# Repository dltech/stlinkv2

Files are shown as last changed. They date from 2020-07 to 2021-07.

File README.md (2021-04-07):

# stlinkv2
ST-link V2 schematic and PCB in kiCAD with initial firmware through UART.
1. PCB templates for prototyping at home are photoresist.svg and lut.svg, also you can convert PCB to any of appropriate formats using KiCAD.
2. As you seen above, for this solution you do not need any other st-link, you need only usb-uart adapter.
3. When you got a board, pull up pin 44 BOOT0 to Vbus by R4 resistor, so after power connect the MCU starts up from the UART bootloader.
4. Power up board by USB and connect it to your PC through UART by RX and TX pads.
5. Write dummy firmware from STLinkV2_bin.zip using the flasher utility (ST UM0462).
6. Return pull down resistor to pin 44 BOOT0 (change location of 10-100K resistor from R4 to R5 place).
7. Then connect it to USB and write the firmware from ST using upgrade utility stlink-V2.J21.S4.zip. Now you got a working st-link clone.

On the linux using the Virtualbox software this method is working too.
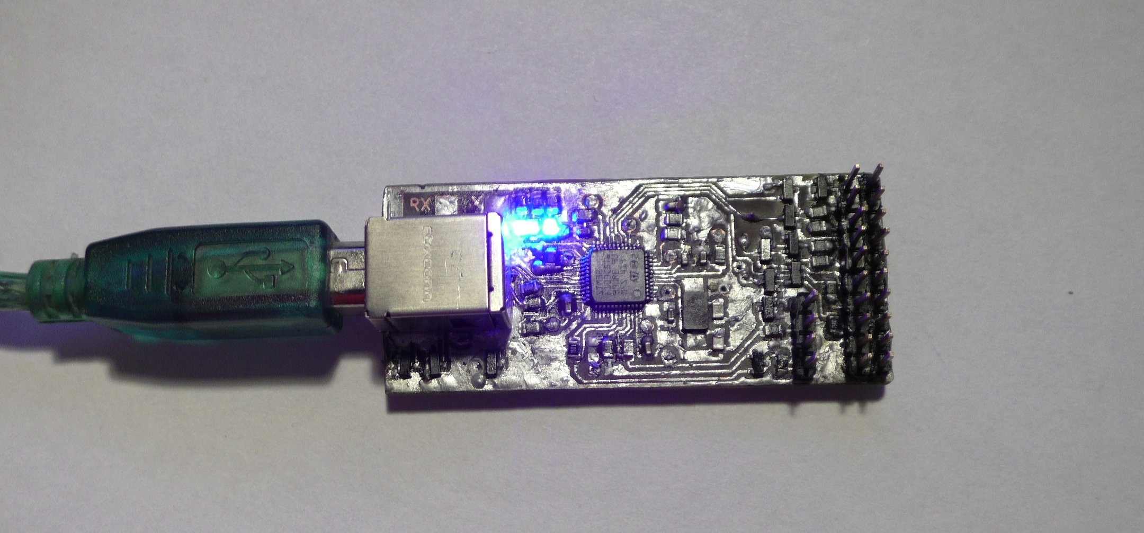
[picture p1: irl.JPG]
device


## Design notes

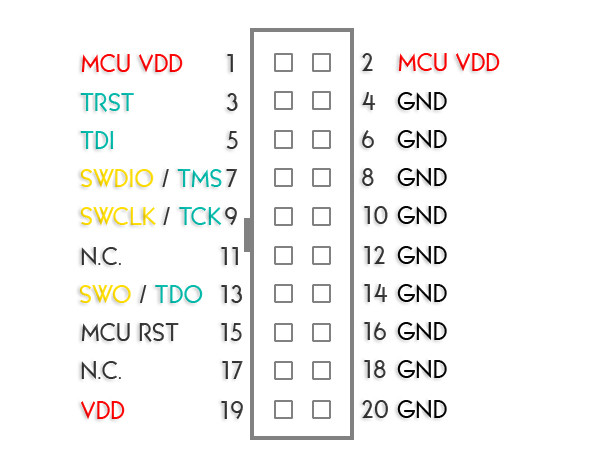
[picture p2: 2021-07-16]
jtag pinout.jpg

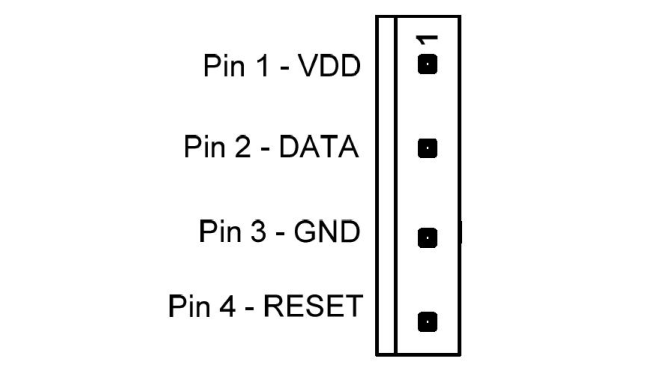
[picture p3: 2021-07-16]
swimm pinout.png

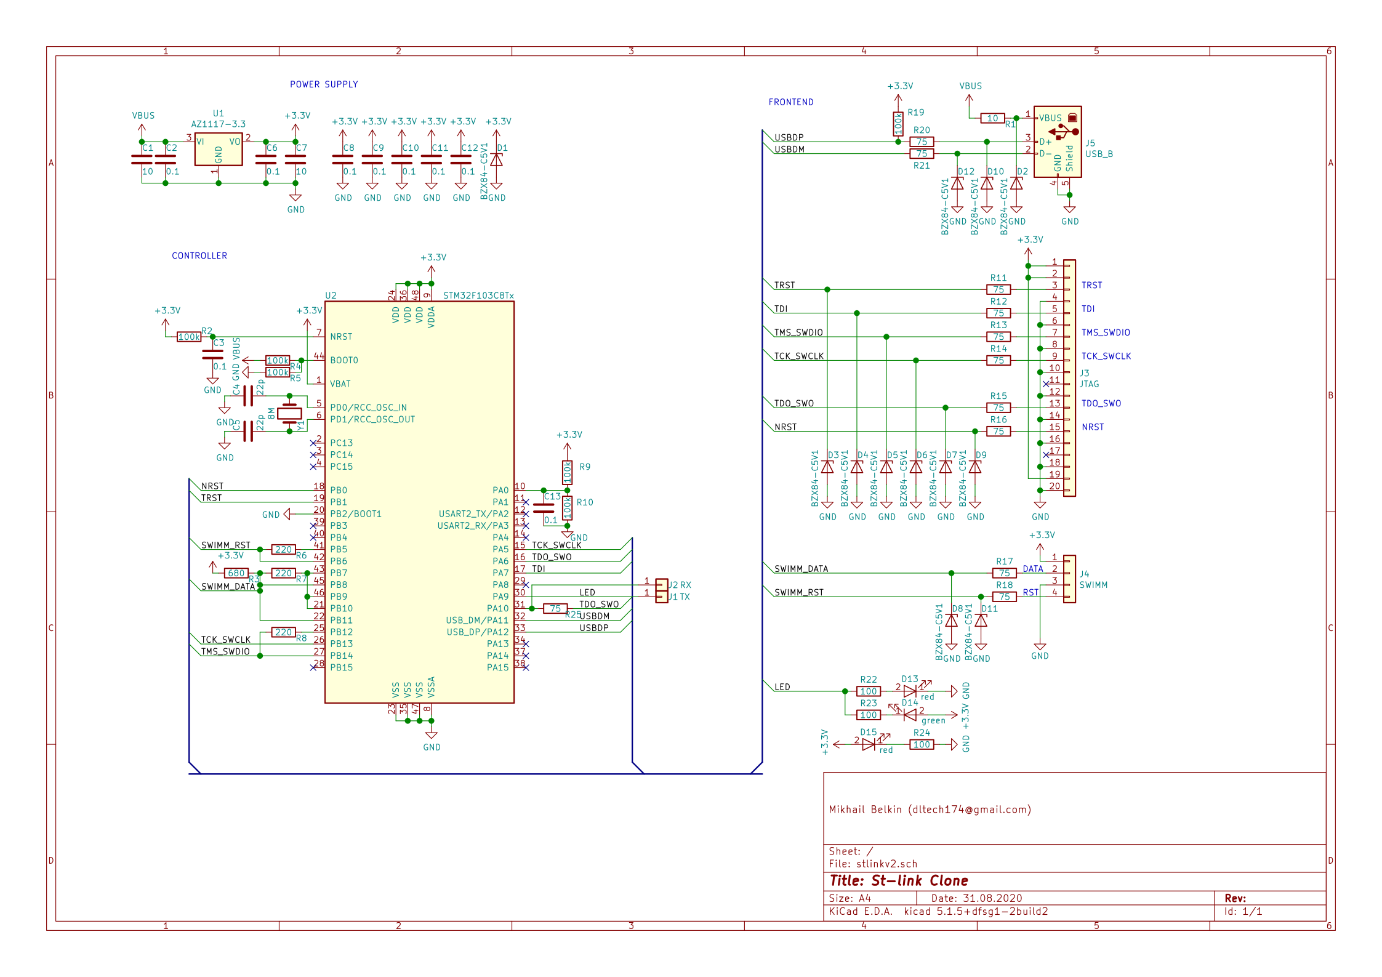
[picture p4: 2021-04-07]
schematic.png

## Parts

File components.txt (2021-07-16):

stm32f103c8t6	x1
BZX85-C5V1	x12
0805 LED	x3 
AMS1117-3.3	x1
8MHZ 5032	x1
0805 CAP 10uF	x2
0805 CAP 0.1uF	x9
0805 CAP 22pF	x2
0805 RES 10	x1
0805 RES 75	x10
0805 RES 100	x3
0805 RES 220	x4
0805 RES 100k	x6
PLS 2.54	x24
USB B		x1

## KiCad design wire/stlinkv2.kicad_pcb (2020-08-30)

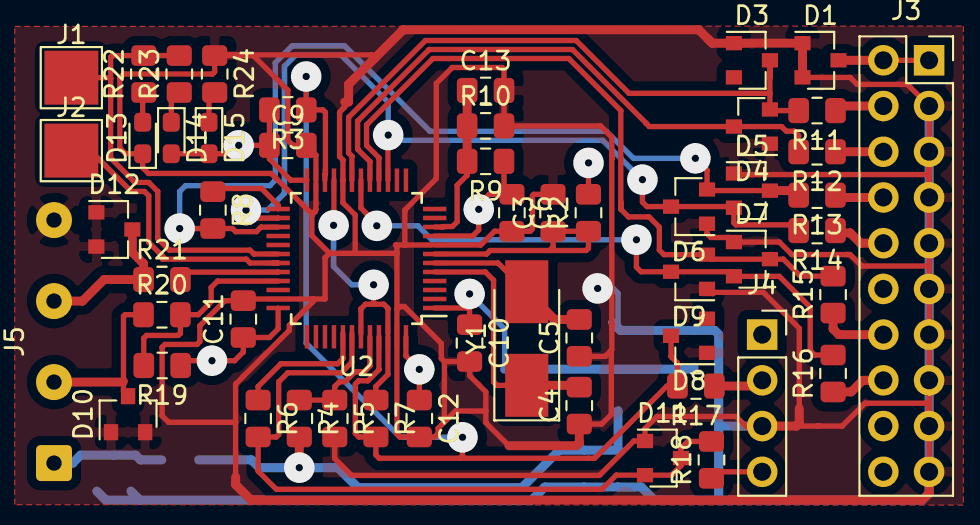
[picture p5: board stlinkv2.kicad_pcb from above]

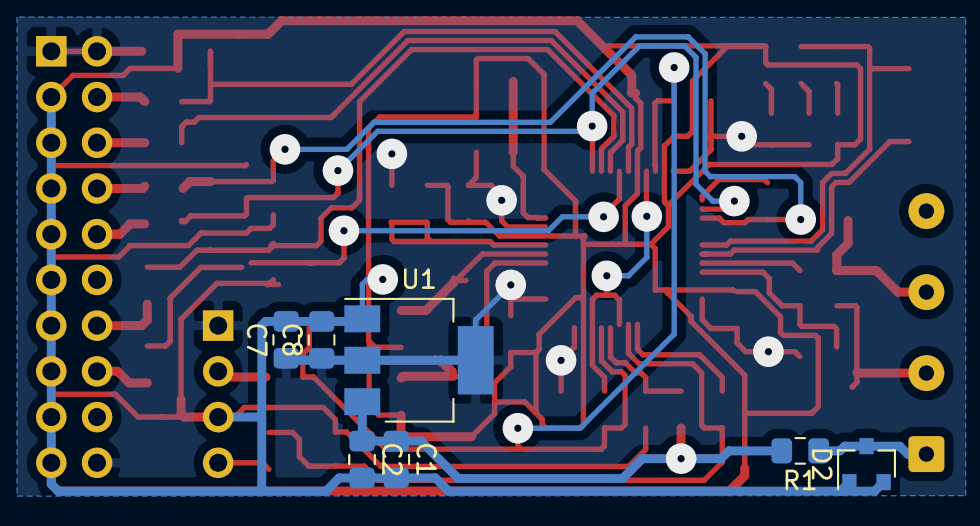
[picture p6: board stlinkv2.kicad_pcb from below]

Board: 2 copper layers, 60 parts (7 on the bottom side), 37 nets.

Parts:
C1, C7: 10; C_0805_2012Metric_Pad1.15x1.40mm_HandSolder
C2, C3, C6, C8, C9, C10, C11, C12, C13: 0.1; C_0805_2012Metric_Pad1.15x1.40mm_HandSolder
C4, C5: 22p; C_0805_2012Metric_Pad1.15x1.40mm_HandSolder
D1, D2, D3, D4, D5, D6, D7, D8, D9, D10, D11, D12: BZX84-C5V1; D_SOT-23_ANK
D13, D15: red; LED_0603_1608Metric_Pad1.05x0.95mm_HandSolder
D14: green; LED_0603_1608Metric_Pad1.05x0.95mm_HandSolder
J1: TX; TestPoint_Pad_3.0x3.0mm
J2: RX; TestPoint_Pad_3.0x3.0mm
J3: JTAG; PinSocket_2x10_P2.54mm_Vertical
J4: SWIMM; PinSocket_1x04_P2.54mm_Vertical
J5: Conn_01x04; SolderWire-0.25sqmm_1x04_P4.5mm_D0.65mm_OD2mm
R1: 10; R_0805_2012Metric_Pad1.15x1.40mm_HandSolder
R2, R4, R5, R9, R10, R19: 100k; R_0805_2012Metric_Pad1.15x1.40mm_HandSolder
R3: 680; R_0805_2012Metric_Pad1.15x1.40mm_HandSolder
R6, R7, R8: 220; R_0805_2012Metric_Pad1.15x1.40mm_HandSolder
R11, R12, R13, R14, R15, R16, R17, R18, R20, R21: 75; R_0805_2012Metric_Pad1.15x1.40mm_HandSolder
R22, R23, R24: 100; R_0805_2012Metric_Pad1.15x1.40mm_HandSolder
U1: AZ1117-3.3; SOT-223-3_TabPin2
U2: STM32F103C8Tx; TQFP-48_7x7mm_P0.5mm
Y1: 8M; Crystal_SMD_5032-2Pin_5.0x3.2mm_HandSoldering

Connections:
+3V3: C6.1, C7.1, C8.1, C9.1, C10.1, C11.1, C12.1, D1.1, D14.2, D15.2, J3.1, J3.2, J3.19, J4.1, R2.2, R3.2, R9.1, R19.1, U1.2, U2.1, U2.9, U2.24, U2.36, U2.48
/LED: J1.1, R22.2, R23.2, U2.30
/NRST: D9.1, R16.2, U2.18
/SWIMM_DATA: D8.1, R3.1, R7.2, R17.2, U2.22, U2.45
/SWIMM_RST: D11.1, R6.2, R18.2, U2.42
/TCK_SWCLK: D6.1, R14.2, U2.15, U2.26
/TDI: D4.1, R12.2, U2.17
/TDO_SWO: D7.1, R15.2, U2.16
/TMS_SWDIO: D5.1, R8.2, R13.2, U2.27
/TRST: D3.1, R11.2, U2.19
/USBDM: R21.2, U2.32
/USBDP: R19.2, R20.2, U2.33
GND: C1.2, C2.2, C3.2, C4.1, C5.1, C6.2, C7.2, C8.2, C9.2, C10.2, C11.2, C12.2, C13.2, D1.2, D2.2, D3.2, D4.2, D5.2, D6.2, D7.2, D8.2, D9.2, D10.2, D11.2, D12.2, D13.1, J3.4, J3.6, J3.8, J3.10, J3.12, J3.14, J3.16, J3.18, J3.20, J4.3, J5.4, R5.2, R10.2, R24.1, U1.1, U2.8, U2.20, U2.23, U2.35, U2.47
unnamed: C3.1, R2.1, U2.7
unnamed: C4.2, U2.5, Y1.1
unnamed: C5.2, U2.6, Y1.2
unnamed: C13.1, R9.2, R10.1, U2.10
unnamed: D2.1, J5.1, R1.1
unnamed: D10.1, J5.2, R20.1
unnamed: D12.1, J5.3, R21.1
unnamed: D13.2, R22.1
unnamed: D14.1, R23.1
unnamed: D15.1, R24.2
unnamed: J2.1, U2.31
unnamed: J3.3, R11.1
unnamed: J3.5, R12.1
unnamed: J3.7, R13.1
unnamed: J3.9, R14.1
unnamed: J3.13, R15.1
unnamed: J3.15, R16.1
unnamed: J4.2, R17.1
unnamed: J4.4, R18.1
unnamed: R4.1, R5.1, U2.44
unnamed: R6.1, U2.41
unnamed: R7.1, U2.21, U2.43, U2.46
unnamed: R8.1, U2.25
VBUS: C1.1, C2.1, R1.2, R4.2, U1.3

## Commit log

2020-07-26 not tested but complete
    [stlinkv2.kicad_pcb, stlinkv2.sch, stlinkv2_sborki.kicad_pcb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]
2020-08-13 добавил светодиоды, проверю без них
    [stlinkv2.kicad_pcb, stlinkv2.sch]
2020-08-13 micro usb
    [stlinkv2.kicad_pcb, stlinkv2.sch]
